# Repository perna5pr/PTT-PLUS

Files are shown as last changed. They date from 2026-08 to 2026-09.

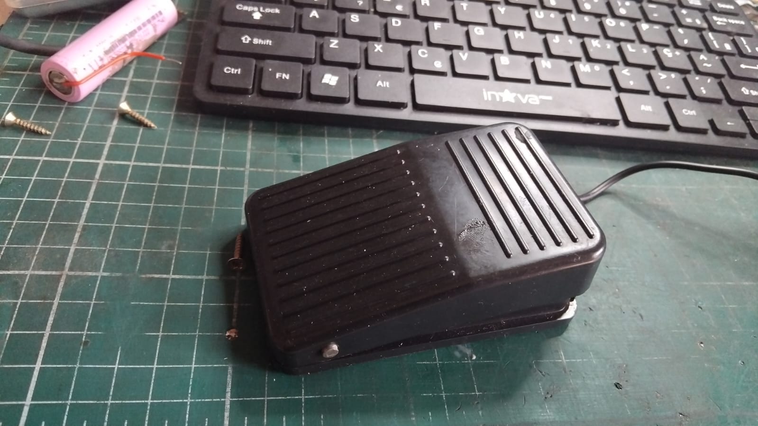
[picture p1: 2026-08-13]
hardware/Pedal-Mouse-PTT/Pedal_Mouse_PTT-foto.jpeg

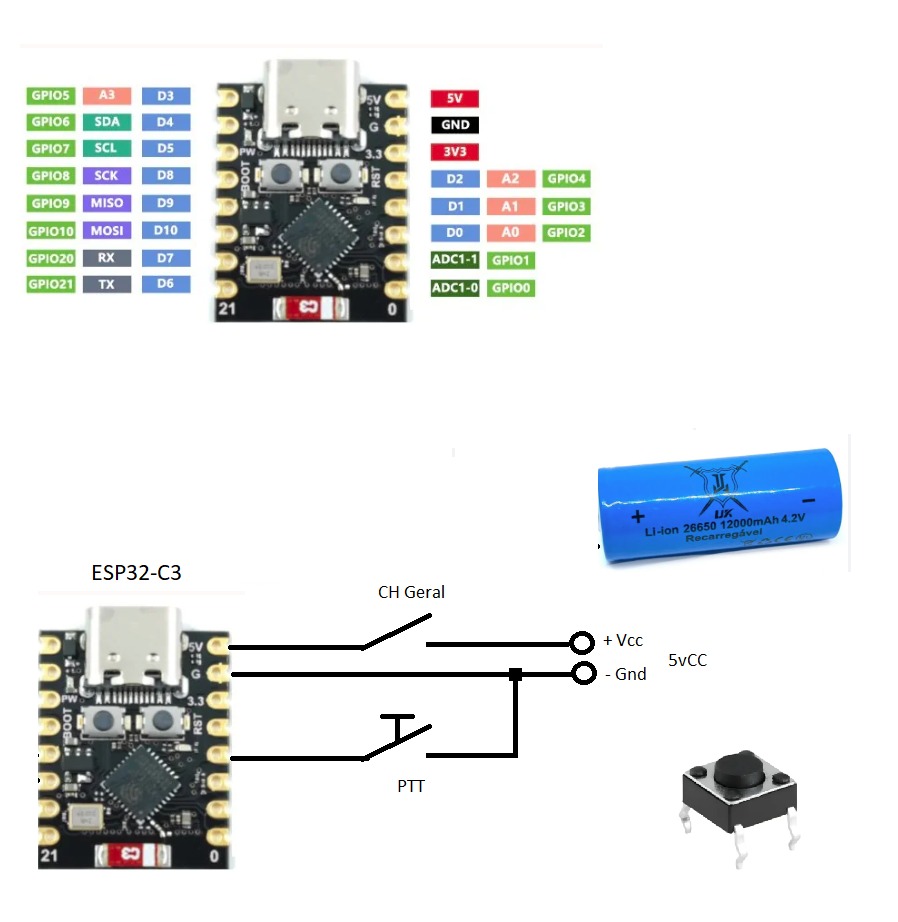
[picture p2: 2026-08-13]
hardware/Pedal-Mouse-PTT/Pedal_Mouse_PTT-diagrama.jpeg

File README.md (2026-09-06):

# 🤖 PTT-PLUS (1bt | 2bt | 4bt)
## Sistema de Automação com ESP32-C3 super mini para o APP CBTalk

Controle de comunicação sem fio de alta precisão baseado em Bluetooth Low Energy (BLE) projetado para automatizar comandos de clique e posicionamento de tela (emulação de mouse HID) no aplicativo CBTalk. O sistema possui temporização inteligente de segurança, interface visual em display compacto de 0.42" e calibração de coordenadas interativa gravada na memória Flash do circuito.

---

## Licenças

### Conteúdo
Este projeto utiliza a licença Creative Commons BY-NC-SA 4.0.


### Software
O código-fonte deste projeto está licenciado sob GPLv3.


### Hardware
O projeto de hardware está licenciado sob CERN-OHL-S.


### Filosofia do projeto
Open Source Hardware can Learn from Software - OSS & OSHW



---

## 🧠 Funcionamento do Algoritmo e Lógica de Controle

O fluxo de execução contínuo do firmware baseia-se em varredura ativa (*polling*) com tempo de ciclo controlado por um `delay(10)` para estabilização de leitura:

1. **Segmentação de Passos HID (Mouse)**: O protocolo Bluetooth clássico limita comandos nativos do mouse a um deslocamento máximo de -127 a +127 pixels por pacote de transmissão. A função `moveMouseSegmented()` fraciona distâncias longas automaticamente e introduz uma pausa de `50ms` para estabilização da interface de toque no smartphone.
2. **Ciclo de Segurança PTT (Anti-Bloqueio)**: Ao ativar a transmissão por voz, o controlador monitora o canal continuamente. Se o temporizador ultrapassar o limite de segurança de `90 segundos`, uma rotina de interrupção força a liberação do clique esquerdo (`mouse.release`) para não ocupar os canais públicos do CBTalk em transmissões acidentais.
3. **Modulação do LED de Feedback**: O pino `GPIO8` opera em modo intermitente comandado por relógio de software (`millis()`). A frequência visual do LED onboard do ESP32-C3 altera-se dinamicamente para sinalizar ao operador o tempo de portadora restante.
4. **Alinhamento Absoluto**: Como dispositivos móveis utilizam coordenadas relativas para emulação de mouses, a rotina `resetCursorPosition()` força intencionalmente o cursor para a borda extrema superior direita `(2000, -2000)` antes de realizar qualquer movimento mapeado. Isso garante que o cálculo em pixel parta sempre do mesmo ponto zero de referência da tela.
5. **Chaveamento Dinâmico do Gatilho**: A variável `PTT_TOGGLE_MODE` define o comportamento do botão principal:
   * **Modo Alternado (`true`)**: Um clique inicial dispara a função `startPTT()`. O estado permanece ativo até que um novo clique execute a rotina `stopPTT()`.
   * **Modo Pressionado (`false`)**: A transmissão ocorre estritamente na transição de descida do sinal (`LOW`), e o encerramento é chamado imediatamente na borda de subida (`HIGH`), emulando um microfone de rádio transceptor tradicional.
6. **Entrada Segura na Calibração**: O modo de ajuste de coordenadas exige que o `BUTTON_PIN3` e o `BUTTON_PIN4` entrem em nível lógico baixo (`LOW`) de forma simultânea. O algoritmo valida se o PTT está inativo (`!isPttActive`) antes de permitir o desvio para a calibração, impedindo que ruídos ou cliques acidentais quebrem a operação de voz.

---

## 🔌 Engenharia de Hardware e Esquema Elétrico (EasyEDA)

O design da placa de circuito impresso (PCB) foi desenvolvido no EasyEDA focado em tamanho reduzido para integração em caixas compactas, utilizando o barramento nativo do ESP32-C3 Super Mini.

### 🎛️ Diagrama de Conexões e Netlist

A distribuição das conexões elétricas das chaves táteis e do barramento de comunicação obedece à seguinte arquitetura de malha tratada no arquivo de fabricação:

*   **Barramento GND Comum:** Todas as 4 chaves táteis (`BT01` a `BT04`) compartilham um nó elétrico de aterramento unificado conectado diretamente ao pino `GND` do ESP32-C3.
*   **Malhas de Sinal (Trilhas de Controle):**
    *   **BT01 (PTT / Cima):** Conectado diretamente ao pino de entrada `GPIO 1`.
    *   **BT02 (Detalhes / Baixo):** Conectado diretamente ao pino de entrada `GPIO 2`.
    *   **BT03 (Lista / Direita):** Conectado diretamente ao pino de entrada `GPIO 3`.
    *   **BT04 (Mute / Esquerda):** Conectado diretamente ao pino de entrada `GPIO 4`.
*   **Interface I2C do Display OLED (0.42"):**
    *   Linha de Dados (`SDA`) roteada de forma isolada para o pino `GPIO 5`.
    *   Linha de Clock (`SCL`) roteada de forma paralela para o pino `GPIO 6`.

### 🛠️ Lista de Materiais de Referência (BOM - Bill of Materials)

| Qtd | Identificador na PCB | Componente Técnico | Tipo / Encapsulamento | Função no Circuito |
| :--- | :--- | :--- | :--- | :--- |
| 1 | U1 | ESP32-C3 Super Mini | SMD Dev Board | Microcontrolador central e interface BLE |
| 4 | BT01 a BT04 | Chaves Táteis Push-Button | 2 pinos / 4.3mm (ou similar) | Entrada de comandos de automação |
| 1 | DISP1 | Display OLED 0.42" 72x40 | SSD1306 I2C (4 pinos) | Feedback visual de estados e contagem |
| 1 | LED1 | LED de Status Integrado | Onboard (GPIO 8) | Alertas regressivos visuais de transmissão |

> ⚠️ **Nota de Montagem:** Como os pinos de entrada `GPIO 1` a `GPIO 4` estão configurados no firmware com resistores internos ativados (`INPUT_PULLUP`), não é necessária a adição de resistores de pull-up externos de 10kΩ na placa, simplificando o layout de trilhas.

---

## 📜 Licença e Termos de Uso

Este projeto é de código e hardware abertos, protegido sob o conceito híbrido **CC BY-NC-SA 4.0** (Atribuição-NãoComercial-CompartilhaIgual):

*   👥 **Atribuição:** Você é livre para montar, testar e alterar este projeto, desde que dê os devidos créditos aos desenvolvedores originais.
*   🛑 **Não Comercial:** É proibida a comercialização de placas montadas baseadas nesses circuitos ou a venda do firmware embarcado sem licenciamento dedicado das partes.
*   🔄 **CompartilhaIgual:** Qualquer projeto derivado ou modificação gerada a partir deste repositório deve obrigatoriamente manter a mesma licença aberta e não-comercial.

Este projeto utiliza licenças diferentes para cada tipo de material. A licença aplicável depende do conteúdo que está sendo utilizado.

### 📄 Conteúdo e documentação

A documentação, textos, imagens, diagramas e demais materiais criativos deste projeto são disponibilizados sob a:

<a href="https://creativecommons.org/licenses/by-nc-sa/4.0/">
  
</a>

**Creative Commons Attribution-NonCommercial-ShareAlike 4.0 International (CC BY-NC-SA 4.0)**

Você pode compartilhar e adaptar este material, desde que:

* dê os devidos créditos ao autor;
* não utilize o material para fins comerciais;
* distribua adaptações sob a mesma licença;
* mantenha os avisos de atribuição e licença aplicáveis.

[Leia o texto completo da CC BY-NC-SA 4.0](https://creativecommons.org/licenses/by-nc-sa/4.0/).

---

### 💻 Software

O código-fonte deste projeto é disponibilizado sob a:

<a href="https://www.gnu.org/licenses/gpl-3.0.html">
  GNU GPLv3
</a>

**GNU General Public License v3.0 (GPLv3)**

O software pode ser usado, estudado, modificado e redistribuído de acordo com os termos da GPLv3.

[Leia o texto completo da GNU GPLv3](https://www.gnu.org/licenses/gpl-3.0.html).

---

### 🔧 Hardware

O hardware, incluindo esquemas, arquivos de projeto, layouts, modelos e demais arquivos necessários para sua fabricação e modificação, é disponibilizado sob a:

<a href="https://ohwr.org/cern_ohl_s_v2.txt">
  CERN Open Hardware Licence
</a>

**CERN Open Hardware Licence Version 2 – Strongly Reciprocal (CERN-OHL-S-2.0)**

O hardware pode ser estudado, fabricado, modificado e redistribuído de acordo com os termos da CERN-OHL-S-2.0, respeitando suas condições de reciprocidade.

[Leia o texto completo da CERN-OHL-S-2.0](https://ohwr.org/cern_ohl_s_v2.txt).

---

### 🌐 Filosofia: Open Source Hardware can Learn from Software

> **Open Source Hardware can Learn from Software**

Este projeto adota a filosofia de que o desenvolvimento de hardware aberto pode se beneficiar dos princípios, práticas e da cultura desenvolvidos no ecossistema de software livre e open source.

<a href="https://www.open-electronics.org/what-can-open-source-hardware-learn-from-software/">
  Open Source Hardware can Learn from Software
</a>

Assim como no software, o projeto busca incentivar:

* **transparência** — disponibilização dos arquivos e informações necessárias para compreender o projeto;
* **liberdade** — possibilidade de estudar, modificar e adaptar o projeto;
* **colaboração** — incentivo à participação e ao desenvolvimento por terceiros;
* **compartilhamento** — possibilidade de distribuir o projeto e suas modificações de acordo com a licença aplicável;
* **reprodutibilidade** — disponibilização dos arquivos necessários para que outras pessoas possam reproduzir o hardware.

**“Open Source Hardware can Learn from Software” não constitui uma licença jurídica adicional.** A licença legal aplicável ao hardware deste projeto é a **CERN-OHL-S-2.0**.

---

### ⚖️ Resumo

| Material | Licença / Princípio |
| --- | --- |
| 📄 Documentação, textos, imagens e outros conteúdos criativos | CC BY-NC-SA 4.0 |
| 💻 Código-fonte e software | GNU GPLv3 |
| 🔧 Hardware e arquivos de projeto | CERN-OHL-S-2.0 |
| 🌐 Filosofia do projeto | Open Source Hardware can Learn from Software |

> **Importante:** cada licença se aplica ao respectivo tipo de material. O conteúdo criativo, o software e o hardware possuem termos de licenciamento distintos. Consulte a licença correspondente antes de redistribuir ou modificar qualquer parte deste projeto.

---

## 👥 Colaboradores e Créditos

Agradecimento especial aos desenvolvedores que projetaram e integraram este sistema (Usuários do CBTalk):

*   ⚡ `~ CASSA VAGABUNDO`
*   ⌨️ `_PERNA-5-PR_`
*   🛠️ `!# _TECNICO_ / SC`

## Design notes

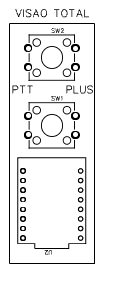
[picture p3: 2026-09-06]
hardware/PTT_PLUS_2bt/PCB_PTT_PLUS_2bt_2026-09-06_frente.png

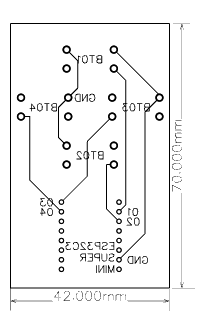
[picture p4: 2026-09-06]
hardware/PTT_PLUS_4bt/PCB_PTT_PLUS_4bt_2026-09-06_tras.png

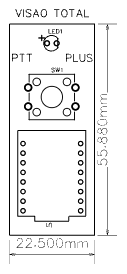
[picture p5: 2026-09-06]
hardware/PTT_PLUS_1bt/PCB_PTT_PLUS_1bt_2026-09-06_frente.png

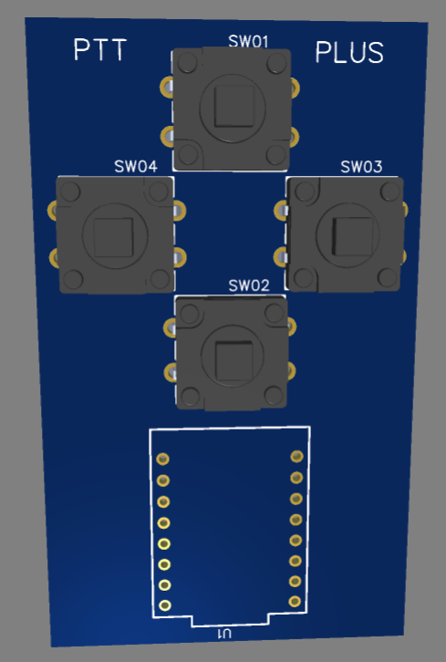
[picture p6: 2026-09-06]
hardware/PTT_PLUS_4bt/PCB_PTT_PLUS_4bt_3D_frente.png

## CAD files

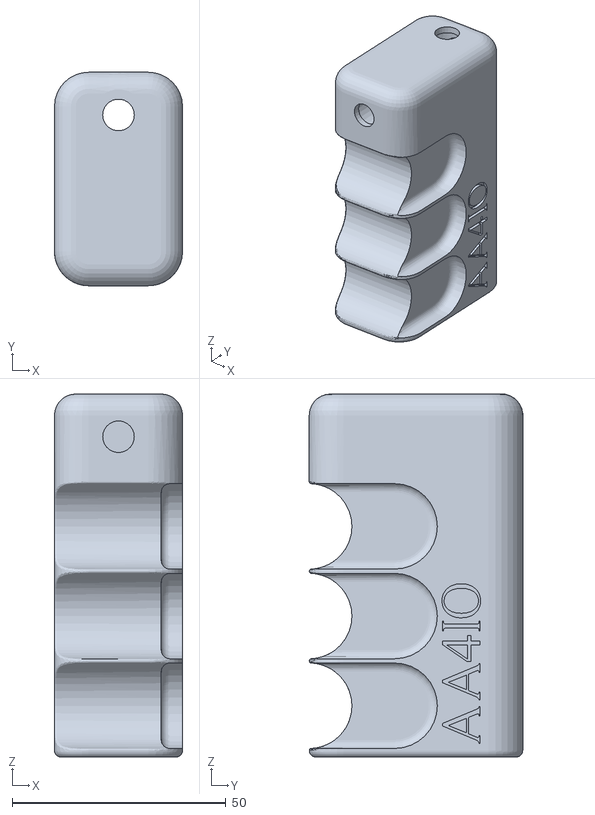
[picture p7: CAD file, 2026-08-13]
hardware/PTT_PLUS_2bt/ptt-2bt.stl
30.0 x 50.0 x 85.0

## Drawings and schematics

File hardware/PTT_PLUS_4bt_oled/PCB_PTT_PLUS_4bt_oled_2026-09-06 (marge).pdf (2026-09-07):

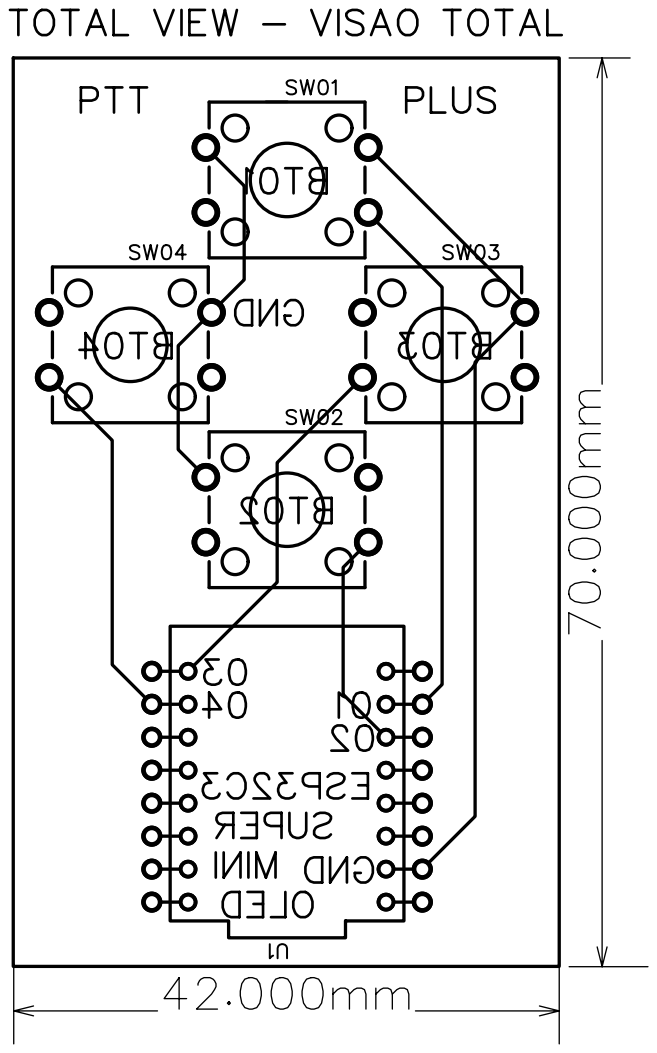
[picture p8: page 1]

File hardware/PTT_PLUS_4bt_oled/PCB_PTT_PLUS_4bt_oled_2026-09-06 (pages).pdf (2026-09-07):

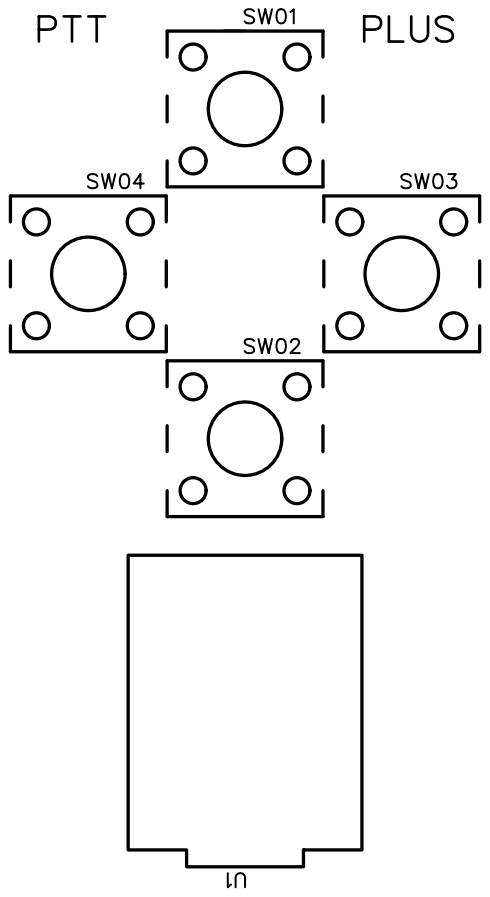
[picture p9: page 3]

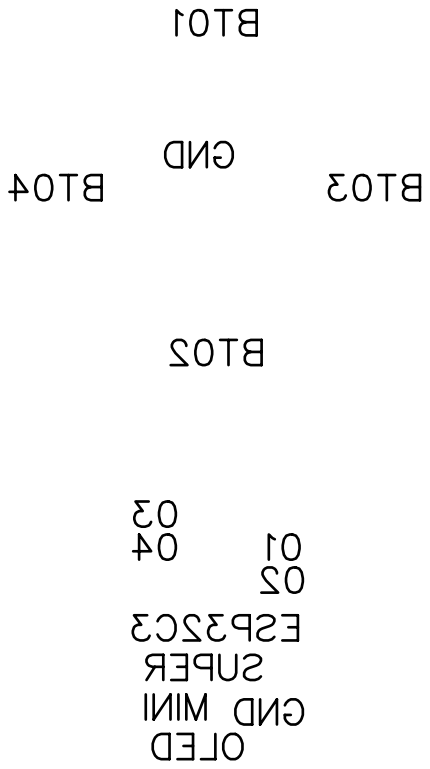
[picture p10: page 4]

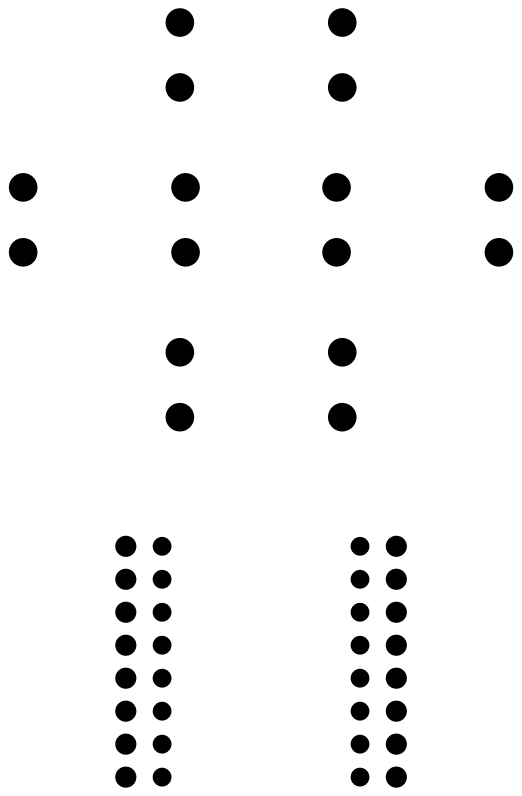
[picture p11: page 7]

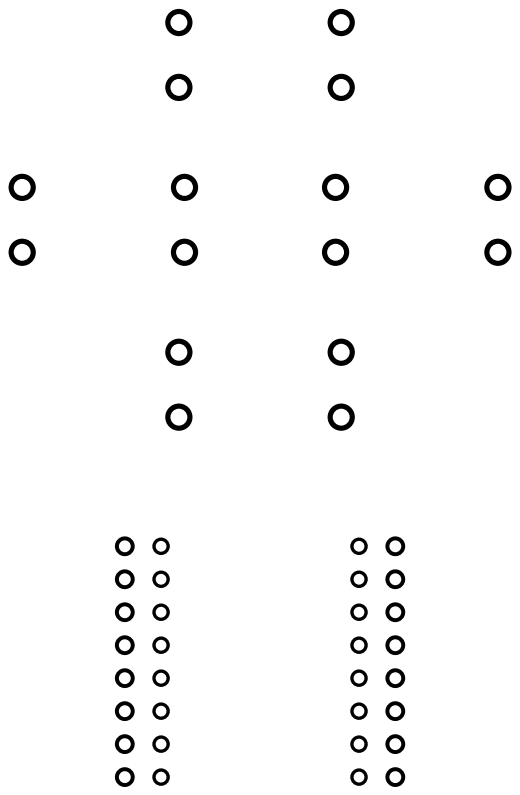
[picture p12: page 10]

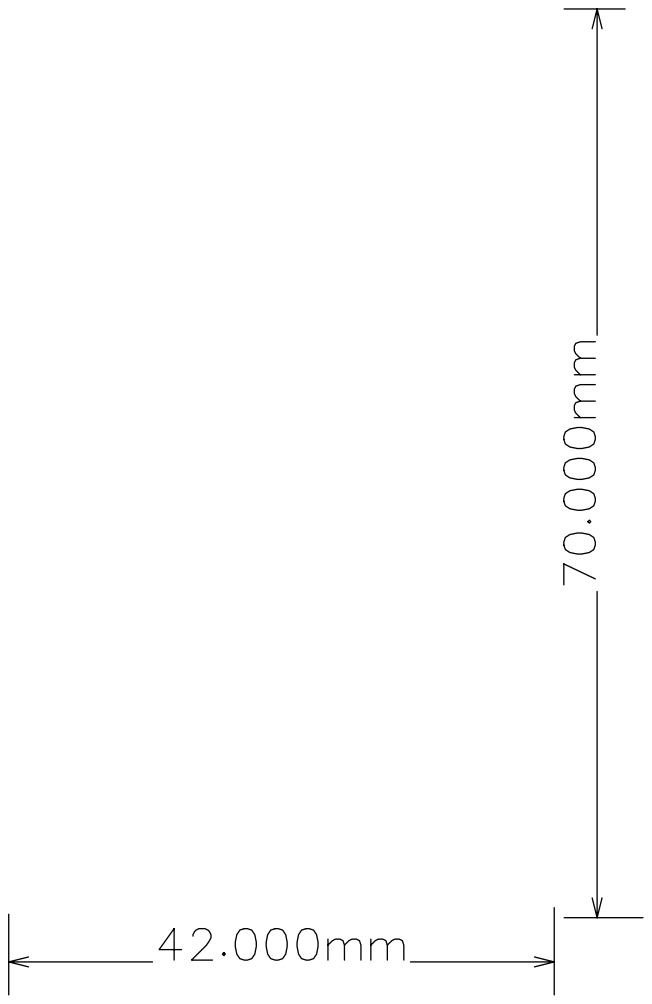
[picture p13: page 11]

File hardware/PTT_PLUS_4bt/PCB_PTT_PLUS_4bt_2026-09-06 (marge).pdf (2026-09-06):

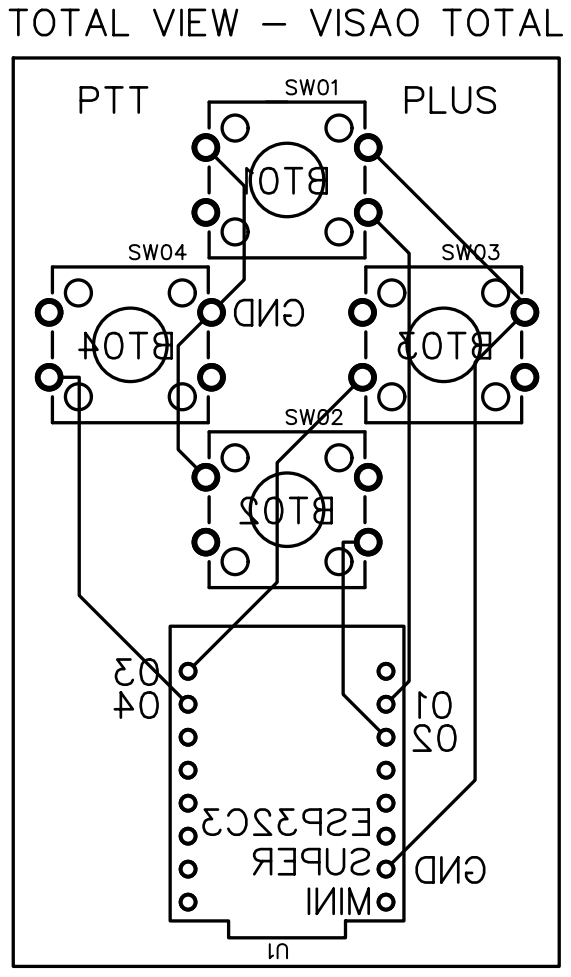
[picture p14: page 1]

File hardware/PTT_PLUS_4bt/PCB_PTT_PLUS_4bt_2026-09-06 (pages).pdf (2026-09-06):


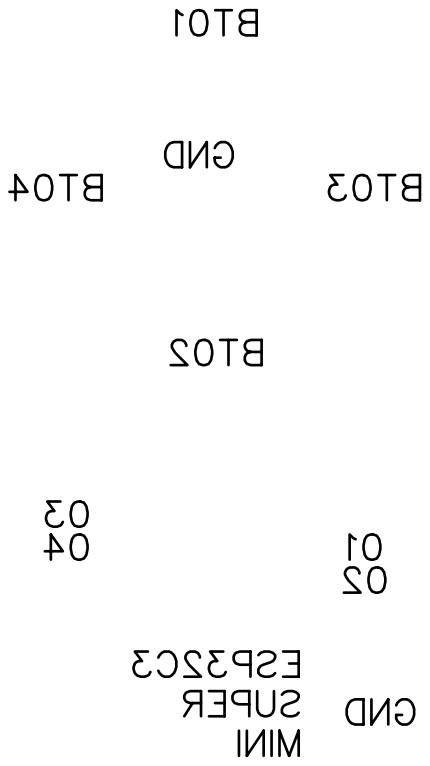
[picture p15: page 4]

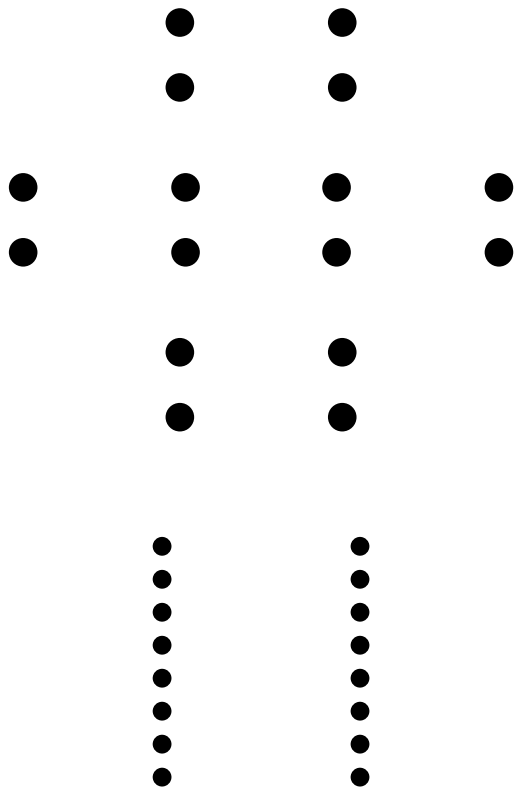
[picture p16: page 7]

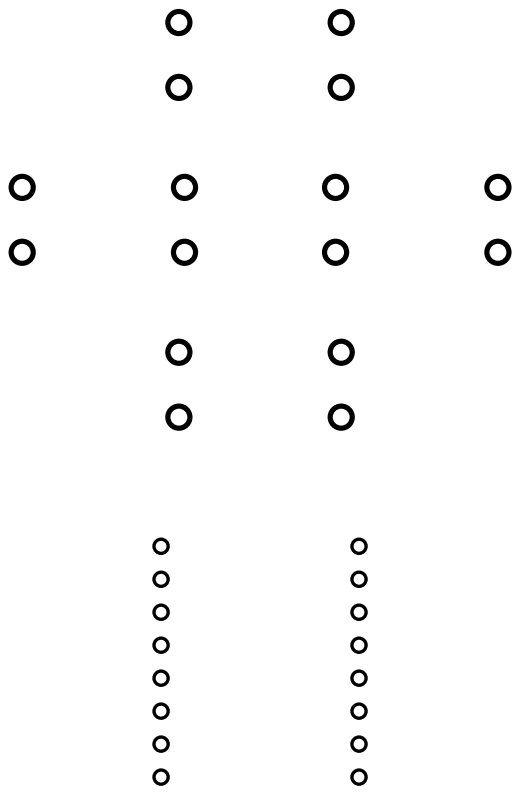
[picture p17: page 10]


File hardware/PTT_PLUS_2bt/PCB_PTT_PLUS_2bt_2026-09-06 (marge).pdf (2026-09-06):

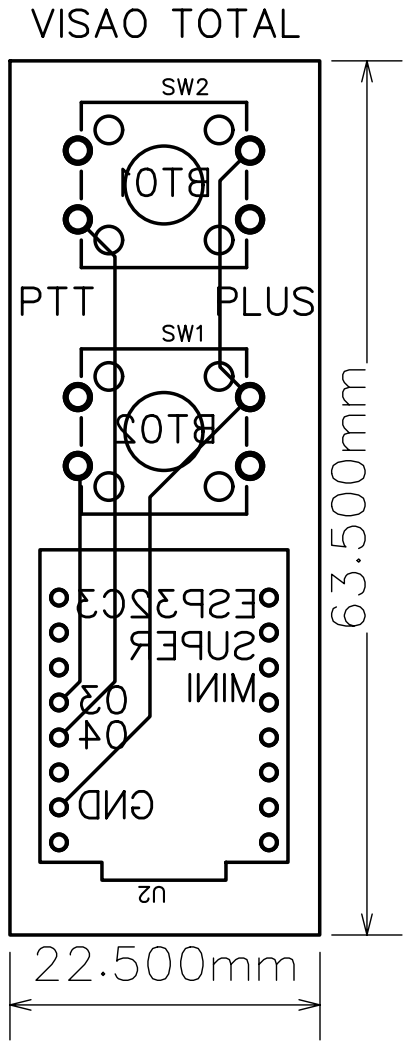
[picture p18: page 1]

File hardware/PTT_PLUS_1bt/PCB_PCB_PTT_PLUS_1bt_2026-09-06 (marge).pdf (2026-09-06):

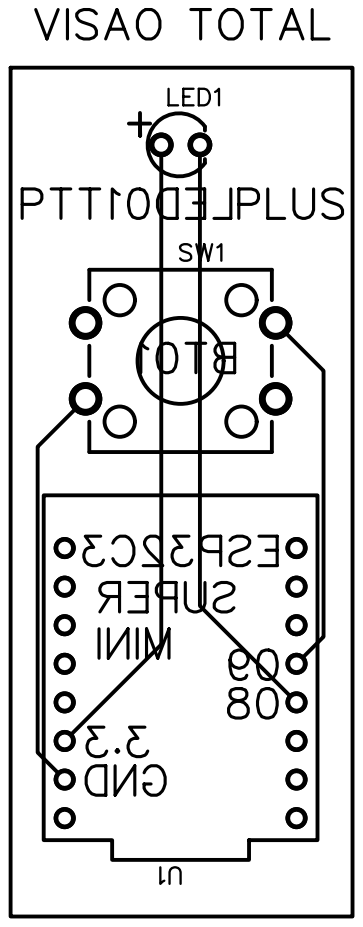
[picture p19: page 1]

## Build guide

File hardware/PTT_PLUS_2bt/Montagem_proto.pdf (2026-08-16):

# PTT 1 botão

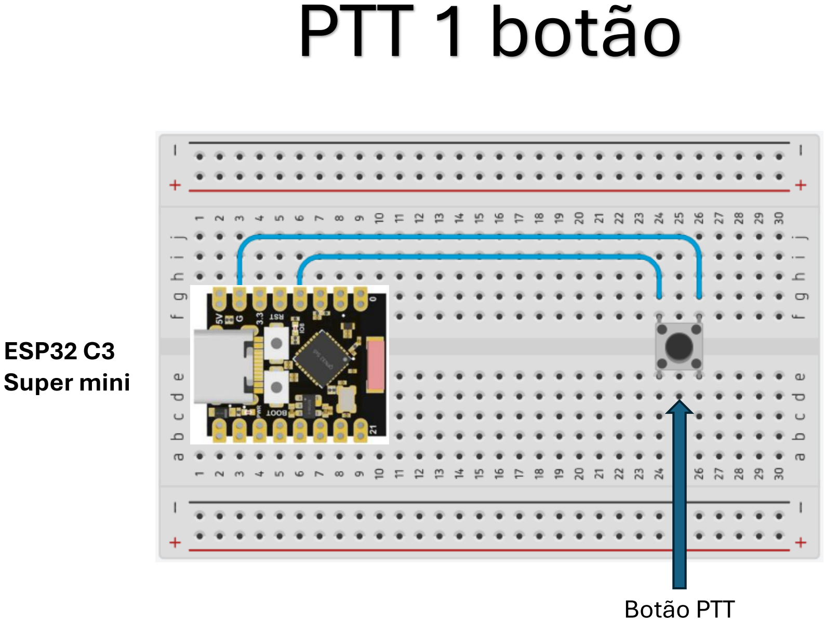
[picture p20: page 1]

Botão PTT

ESP32 C3
Super mini

# PTT 2 botões

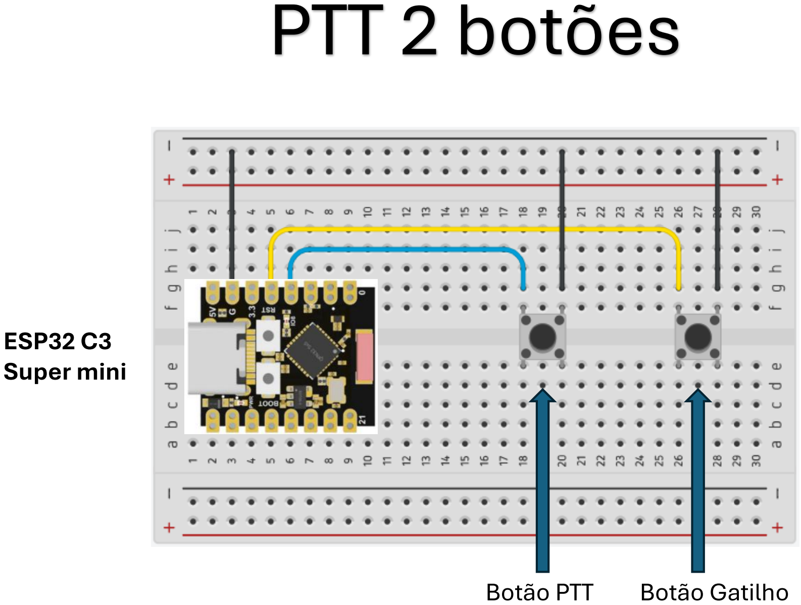
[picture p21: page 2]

Botão PTT Botão Gatilho

ESP32 C3
Super mini

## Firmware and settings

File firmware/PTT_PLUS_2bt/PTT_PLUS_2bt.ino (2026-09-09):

#include <Arduino.h>
#include <HijelHID_BLEMouse.h>
#include <Preferences.h>

// Instância do Mouse BLE com nome e fabricante personalizados
HijelBLEMouse mouse("PTT_PLUS_2bt", "MOSAICO", 100);

// Configuração dos Pinos dos Botões (GPIO 3 e GPIO 4 no ESP32-C3)
const int BUTTON_PIN1 = 3;
const int BUTTON_PIN2 = 4;
const int PINO_BOOT = 9;  // Botão BOOT onboard do ESP32-C3 SuperMini, usado para calibração

Preferences preferences;

// --- LED onboard simples (azul, GPIO8 no ESP32-C3 SuperMini) ---
const int LED_PIN = 8;
const bool LED_ACTIVE_LOW = true;  // na maioria das SuperMini o LED acende com GPIO em LOW.
                                    // Se o LED ficar invertido (aceso quando devia estar apagado), mude para false.

bool ledOn = false;                 // estado lógico atual do LED (para controlar o pisca-pisca)
unsigned long lastLedToggle = 0;

const unsigned long LED_WARN_SLOW_THRESHOLD_MS = 30000;  // a partir daqui (30s restantes) começa a piscar devagar
const unsigned long LED_WARN_FAST_THRESHOLD_MS = 10000;  // a partir daqui (10s restantes) pisca rápido
const unsigned long LED_BLINK_SLOW_MS = 500;              // intervalo do pisca devagar
const unsigned long LED_BLINK_FAST_MS = 150;               // intervalo do pisca rápido

// --- Posições calibráveis dos cliques na tela (salvas na memória flash) ---
int16_t ptt1X = -25;
int16_t ptt1Y = 130;
int16_t btn2X = -125;
int16_t btn2Y = 65;

// --- Controle de entrada no modo calibração (segurar BOOT por 5s) ---
bool bootHeld = false;
unsigned long bootPressStart = 0;
const unsigned long BOOT_HOLD_TO_CALIBRATE_MS = 5000;

// --- BOTÃO 1 (PTT) ---
bool isPressed1 = false;      // true enquanto o PTT está ativo (transmitindo)
bool isLocked1 = false;       // true quando travado via clique rápido
int lastButtonState1 = HIGH;  // última leitura bruta (para debounce)
bool stableState1 = HIGH;     // último estado já confirmado/debounced
unsigned long lastDebounceTime1 = 0;
unsigned long pressStartTime1 = 0;  // quando o botão foi pressionado (p/ distinguir clique de hold)
unsigned long timePTT = 0;          // quando o PTT ligou (p/ trava de segurança de 90s e contagem do LED)

// --- BOTÃO 2 ---
bool isPressed2 = false;
int lastButtonState2 = HIGH;
unsigned long lastDebounceTime2 = 0;

const unsigned long DEBOUNCE_DELAY = 50;
const unsigned long CLICK_THRESHOLD_MS = 300;  // abaixo disso = "clique" (trava); acima = "hold"
const unsigned long PTT_MAX_HOLD_MS = 90000;   // trava de segurança: solta sozinho após 90s

// Variável de controle para posicionamento inicial único pós-conexão
bool isPositioned = false;

// Armazena o estado anterior da conexão Bluetooth
bool lastPairedState = false;

void setup() {
  Serial.begin(115200);
  Serial.println("Iniciando PTT_PLUS 2bt");

  // Configura os botões com Pull-Up interno
  pinMode(BUTTON_PIN1, INPUT_PULLUP);
  pinMode(BUTTON_PIN2, INPUT_PULLUP);
  pinMode(PINO_BOOT, INPUT_PULLUP);

  // Inicializa o LED apagado
  pinMode(LED_PIN, OUTPUT);
  setLed(false);

  loadCalibrationFromNVS();

  // Inicializa o serviço BLE Mouse
  mouse.begin();

  delay(1000);
}

// Liga/desliga o LED fisicamente, respeitando a polaridade da placa
void setLed(bool on) {
  bool physicalHigh = LED_ACTIVE_LOW ? !on : on;
  digitalWrite(LED_PIN, physicalHigh ? HIGH : LOW);
  ledOn = on;
}

// Move o cursor em passos de no maximo 127 unidades (limite do protocolo HID),
// dividindo automaticamente deslocamentos maiores.
void moveMouseSegmented(int16_t totalX, int16_t totalY) {
  int16_t remX = totalX;
  int16_t remY = totalY;
  while (remX != 0 || remY != 0) {
    int8_t stepX = (int8_t)constrain(remX, -127, 127);
    int8_t stepY = (int8_t)constrain(remY, -127, 127);
    mouse.moveTo(stepX, stepY);
    remX -= stepX;
    remY -= stepY;
    delay(50);
  }
}

void loadCalibrationFromNVS() {
  preferences.begin("ptt_calib", true);
  ptt1X = preferences.getShort("b1_x", -25);
  ptt1Y = preferences.getShort("b1_y", 130);
  btn2X = preferences.getShort("b2_x", -125);
  btn2Y = preferences.getShort("b2_y", 65);
  preferences.end();
  Serial.printf("Posições carregadas: Botao1 X=%d Y=%d | Botao2 X=%d Y=%d\n", ptt1X, ptt1Y, btn2X, btn2Y);
}

void saveCalibrationToNVS() {
  preferences.begin("ptt_calib", false);
  preferences.putShort("b1_x", ptt1X);
  preferences.putShort("b1_y", ptt1Y);
  preferences.putShort("b2_x", btn2X);
  preferences.putShort("b2_y", btn2Y);
  preferences.end();
  Serial.println("Posições salvas na memória flash (NVS)!");
}

// Modo de calibração: segurar o BOOT por 5s entra aqui. Configuração 100% pelo
// Serial Monitor (digite 'X,Y' + Enter para mover o cursor até lá, e 'ok' ou o
// próprio BOOT para confirmar). Passa pelos 2 botões em sequência.
void runCalibrationMode() {
  Serial.println("\n=======================================================");
  Serial.println(">>> MODO DE CALIBRAÇÃO ATIVADO (BOOT segurado por 5s)! <<<");
  Serial.println("=======================================================\n");

  Serial.println("Entrando no modo de calibracao... aguarde.");
  setLed(true);
  delay(3000);
  setLed(false);

  while (digitalRead(PINO_BOOT) == LOW) {
    delay(10);
  }
  delay(200);

  Serial.println("----------------------------------------------------------------------------------");
  Serial.println("Para cada botão, digite 'X,Y' + Enter (ex: -25,130) para mover o cursor até lá,");
  Serial.println("a partir do canto. Repita quantas vezes quiser até acertar. Depois digite 'ok'");
  Serial.println("(ou aperte o BOOT) para confirmar e passar para o próximo.");
  Serial.println("O LED faz N piscadas no primeiro segundo (N = numero do botao) e apaga no seguinte.");
  Serial.println("----------------------------------------------------------------------------------\n");

  int16_t targetCoordsX[2] = { ptt1X, btn2X };
  int16_t targetCoordsY[2] = { ptt1Y, btn2Y };

  for (int i = 0; i < 2; i++) {
    Serial.printf(">>> CONFIGURANDO BOTÃO %d <<< (LED pisca %d vez(es) por segundo)\n", i + 1, i + 1);

    mouse.moveTo(2000, -2000);  // reseta o cursor no canto
    delay(300);

    while (digitalRead(PINO_BOOT) == LOW) {
      delay(10);
    }
    delay(200);

    const unsigned long blinksThisButton = (unsigned long)(i + 1);
    const unsigned long halfPeriod = 500UL / blinksThisButton;
    bool lastLedComputed = false;

    int16_t currentX = 0;
    int16_t currentY = 0;
    bool stepConfirmed = false;

    while (!stepConfirmed) {
      bool confirmNow = (digitalRead(PINO_BOOT) == LOW);

      if (Serial.available()) {
        String cmd = Serial.readStringUntil('\n');
        cmd.trim();
        if (cmd.length() > 0) {
          String cmdLower = cmd;
          cmdLower.toLowerCase();
          if (cmdLower == "ok" || cmdLower == "enter") {
            confirmNow = true;
          } else {
            int commaIndex = cmd.indexOf(',');
            if (commaIndex > 0) {
              int16_t targetX = (int16_t)cmd.substring(0, commaIndex).toInt();
              int16_t targetY = (int16_t)cmd.substring(commaIndex + 1).toInt();
              int16_t deltaX = targetX - currentX;
              int16_t deltaY = targetY - currentY;
              moveMouseSegmented(deltaX, deltaY);
              currentX = targetX;
              currentY = targetY;
              Serial.printf("  Cursor movido para X=%d Y=%d (a partir do canto)\n", currentX, currentY);
            } else {
              Serial.println("  Comando nao reconhecido. Use 'X,Y' (ex: -25,130) ou 'ok'.");
            }
          }
        }
      }

      // LED: N piscadas no primeiro segundo do ciclo de 2s, apagado no segundo seguinte
      unsigned long cyclePos = millis() % 2000;
      bool shouldBeOn;
      if (cyclePos < 1000) {
        shouldBeOn = ((cyclePos / halfPeriod) % 2) == 0;
      } else {
        shouldBeOn = false;
      }
      if (shouldBeOn != lastLedComputed) {
        lastLedComputed = shouldBeOn;
        setLed(shouldBeOn);
      }

      if (confirmNow) {
        targetCoordsX[i] = currentX;
        targetCoordsY[i] = currentY;
        Serial.printf("-> Botão %d SALVO! X=%d Y=%d\n\n", i + 1, currentX, currentY);

        for (int flash = 0; flash < 3; flash++) {
          setLed(true);
          delay(80);
          setLed(false);
          delay(80);
        }

        stepConfirmed = true;
        while (digitalRead(PINO_BOOT) == LOW) {
          delay(10);
        }
        delay(300);
      }

      delay(10);
    }
  }

  ptt1X = targetCoordsX[0];
  ptt1Y = targetCoordsY[0];
  btn2X = targetCoordsX[1];
  btn2Y = targetCoordsY[1];

  saveCalibrationToNVS();

  Serial.println("\n=======================================================");
  Serial.println("Calibração concluída! Os 2 botões foram salvos.");
  Serial.println("=======================================================\n");

  setLed(false);
  mouse.moveTo(2000, -2000);
}

// Atualiza o LED a cada volta do loop, sem bloquear nada.
// Regras:
//  - Fora de transmissão -> apagado
//  - Segurando (hold, sem estar travado) -> aceso fixo
//  - Travado (clique) -> aceso fixo até faltarem 30s do timeout de 90s,
//    depois pisca devagar, e piscando rápido nos últimos 10s
void atualizarLed() {
  if (!isPressed1) {
    if (ledOn) setLed(false);
    return;
  }

  if (!isLocked1) {
    // Modo "segurando": aceso fixo enquanto o dedo estiver no botão
    if (!ledOn) setLed(true);
    return;
  }

  // Modo travado: calcula quanto tempo falta para o timeout de segurança
  unsigned long elapsed = millis() - timePTT;
  long remaining = (long)PTT_MAX_HOLD_MS - (long)elapsed;
  if (remaining < 0) remaining = 0;

  if (remaining > LED_WARN_SLOW_THRESHOLD_MS) {
    // Mais de 30s restantes -> aceso fixo
    if (!ledOn) setLed(true);
  } else {
    unsigned long blinkInterval =
        (remaining > LED_WARN_FAST_THRESHOLD_MS) ? LED_BLINK_SLOW_MS : LED_BLINK_FAST_MS;
    if (millis() - lastLedToggle >= blinkInterval) {
      lastLedToggle = millis();
      setLed(!ledOn);
    }
  }
}

// Liga o PTT: posiciona o cursor e pressiona o clique esquerdo
void ativarPTT() {
  isPressed1 = true;
  moveMouseSegmented(ptt1X, ptt1Y);
  mouse.press(MouseButton::Left);  // press()/release() não bloqueiam
  Serial.println("Botao 1: PTT ativado");
}

// Solta o PTT e devolve o cursor para o canto
void liberarPTT() {
  isPressed1 = false;
  mouse.release(MouseButton::Left);
  delay(50);
  mouse.moveTo(2000, -2000);
  delay(50);
  Serial.println("Botao 1: PTT liberado. Cursor de volta ao canto.");
}

void loop() {
  bool isConnected = mouse.isPaired();

  // Executado quando o status do Bluetooth muda (Conectou ou Desconectou)
  if (isConnected != lastPairedState) {
    lastPairedState = isConnected;
    if (isConnected) {
      Serial.println("CBTalk - CONECTADO - PRONTO");
      if (!isPositioned) {
        Serial.println("Celular conectado! Alinhando cursor no canto superior direito...");
        delay(400);  // Aguarda estabilização da conexão BLE do Android

        mouse.moveTo(2000, -2000);
        delay(50);

        isPositioned = true;
        Serial.println("Cursor posicionado sobre o PTT! Transmissão instantânea pronta.");
      }
    } else {
      Serial.println("CBTalk - DESCONECTADO - Aguardando");
      if (isPositioned) {
        Serial.println("Bluetooth desconectado. Aguardando reconexão...");
        isPositioned = false;
      }
      // Se caiu a conexão com o PTT ativo, zera o estado local
      isPressed1 = false;
      isLocked1 = false;
      isPressed2 = false;
    }
  }

  // Executa as ações apenas quando o celular estiver conectado
  if (isConnected) {
    // Entrada na calibração: segurar o botão BOOT por 5 segundos
    bool bootPressedNow = (digitalRead(PINO_BOOT) == LOW);
    if (bootPressedNow && !isPressed1) {
      if (!bootHeld) {
        bootHeld = true;
        bootPressStart = millis();
      } else if (millis() - bootPressStart >= BOOT_HOLD_TO_CALIBRATE_MS) {
        bootHeld = false;
        runCalibrationMode();
        return;
      }
    } else {
      bootHeld = false;
    }

    int reading1 = digitalRead(BUTTON_PIN1);
    int reading2 = digitalRead(BUTTON_PIN2);

    // --- TRATAMENTO DO BOTÃO 1 (PTT: clique-trava + segurar-para-transmitir) ---
    if (reading1 != lastButtonState1) {
      lastDebounceTime1 = millis();
    }

    // Só processa quando o sinal estabilizou (debounce) E realmente mudou de estado
    if ((millis() - lastDebounceTime1) > DEBOUNCE_DELAY && reading1 != stableState1) {
      stableState1 = reading1;

      if (stableState1 == LOW) {
        // --- Borda de descida: botão foi pressionado agora ---
        if (isLocked1) {
          // Segundo clique enquanto travado -> destrava e solta
          isLocked1 = false;
          liberarPTT();
        } else if (!isPressed1) {
          // Início de um novo toque: liga o PTT na hora.
          // Ainda não sabemos se vai virar "clique" (trava) ou "hold" (soltar ao soltar o dedo).
          pressStartTime1 = millis();
          timePTT = millis();
          ativarPTT();
        }
      } else {
        // --- Borda de subida: botão foi solto agora ---
        if (isPressed1 && !isLocked1) {
          unsigned long heldFor = millis() - pressStartTime1;
          if (heldFor < CLICK_THRESHOLD_MS) {
            // Foi um clique rápido -> trava ligado, não solta o PTT
            isLocked1 = true;
            lastLedToggle = millis();  // começa o ciclo de pisca do LED do zero
            Serial.println("Botao 1: Clique detectado - PTT TRAVADO");
          } else {
            // Foi um hold -> solta o PTT agora que o dedo saiu
            liberarPTT();
          }
        }
      }
    }
    lastButtonState1 = reading1;

    // Trava de segurança: solta o PTT automaticamente após PTT_MAX_HOLD_MS,
    // seja no modo travado (clique) ou segurando (hold)
    if (isPressed1 && (millis() - timePTT) >= PTT_MAX_HOLD_MS) {
      Serial.println("Botao 1: Timeout de seguranca atingido, liberando PTT");
      isLocked1 = false;
      liberarPTT();
    }

    // --- TRATAMENTO DO BOTÃO 2 ---
    if (reading2 != lastButtonState2) {
      lastDebounceTime2 = millis();
    }

    if ((millis() - lastDebounceTime2) > DEBOUNCE_DELAY) {
      if (reading2 == LOW && !isPressed2 && !isPressed1) {
        isPressed2 = true;
        Serial.println("Botão 2: Detalhes do Usuario!");
        moveMouseSegmented(btn2X, btn2Y);
        mouse.click(MouseButton::Left, 50);
        delay(50);
      } else if (reading2 == HIGH && isPressed2) {
        isPressed2 = false;
        Serial.println("Botão 2 Solto!");
        mouse.moveTo(2000, -2000);
        delay(50);
      }
    }
    lastButtonState2 = reading2;

  } else {
    // Reseta as flags se perder a conexão Bluetooth
    isPressed1 = false;
    isLocked1 = false;
    isPressed2 = false;
  }

  // Atualiza o LED em toda volta do loop (não bloqueia nada)
  atualizarLed();

  delay(10);
}

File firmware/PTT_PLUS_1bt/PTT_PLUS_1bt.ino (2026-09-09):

#include <Arduino.h>
#include <HijelHID_BLEMouse.h>
#include <Preferences.h>

// Instância do Mouse BLE com nome e fabricante personalizados
HijelBLEMouse mouse("PTT_PLUS_1bt", "MOSAICO", 100);

#define PINO_PTT 9  // Mesmo pino do botao BOOT onboard do ESP32-C3 SuperMini
#define PINO_LED 8

Preferences preferences;

const bool LED_ACTIVE_LOW = true;  // no ESP32-C3 SuperMini o LED onboard do GPIO8 acende em LOW.
                                    // Se ficar invertido (aceso quando devia estar apagado), mude para false.

bool ledOn = false;
unsigned long lastLedToggle = 0;

const unsigned long LED_BLINK_WAITING_MS = 300;           // velocidade do pisca enquanto aguarda conexao
const unsigned long LED_WARN_SLOW_THRESHOLD_MS = 30000;   // a partir daqui (30s restantes) comeca a piscar devagar
const unsigned long LED_WARN_FAST_THRESHOLD_MS = 10000;   // a partir daqui (10s restantes) pisca rapido
const unsigned long LED_BLINK_SLOW_MS = 500;               // intervalo do pisca devagar
const unsigned long LED_BLINK_FAST_MS = 150;                // intervalo do pisca rapido

// --- Posição do clique do PTT na tela (calibrável, salva na memória flash) ---
int16_t pttX = -70;
int16_t pttY = 240;

// --- Controle de entrada no modo calibração ---
// Como este projeto so tem 1 botao (PINO_PTT = 9, o mesmo do BOOT onboard),
// a calibracao e acionada segurando o PROPRIO botao de PTT por 5s continuos.
const unsigned long BOOT_HOLD_TO_CALIBRATE_MS = 5000;
bool calibrationArmed = false;  // vira true assim que o hold ultrapassa 5s nesta pressao

// --- PTT ---
bool isPressed = false;       // true enquanto o PTT esta ativo (transmitindo)
bool isLocked = false;        // true quando travado via clique rapido
int lastButtonState = HIGH;   // ultima leitura bruta (para debounce)
bool stableState = HIGH;      // ultimo estado ja confirmado/debounced
unsigned long lastDebounceTime = 0;
unsigned long pressStartTime = 0;  // quando o botao foi pressionado (p/ distinguir clique de hold)
unsigned long timePTT = 0;         // quando o PTT ligou (p/ trava de seguranca de 90s e contagem do LED)

const unsigned long DEBOUNCE_DELAY = 50;
const unsigned long CLICK_THRESHOLD_MS = 300;  // abaixo disso = "clique" (trava); acima = "hold"
const unsigned long PTT_MAX_HOLD_MS = 90000;   // trava de seguranca: solta sozinho apos 90s

bool isConnected = false;
bool isPositioned = false;   // controle do posicionamento inicial do cursor pos-conexao
bool lastPairedState = false;

// Liga/desliga o LED fisicamente, respeitando a polaridade da placa
void setLed(bool on) {
  bool physicalHigh = LED_ACTIVE_LOW ? !on : on;
  digitalWrite(PINO_LED, physicalHigh ? HIGH : LOW);
  ledOn = on;
}

// Move o cursor em passos de no maximo 127 unidades (limite do protocolo HID),
// dividindo automaticamente deslocamentos maiores.
void moveMouseSegmented(int16_t totalX, int16_t totalY) {
  int16_t remX = totalX;
  int16_t remY = totalY;
  while (remX != 0 || remY != 0) {
    int8_t stepX = (int8_t)constrain(remX, -127, 127);
    int8_t stepY = (int8_t)constrain(remY, -127, 127);
    mouse.moveTo(stepX, stepY);
    remX -= stepX;
    remY -= stepY;
    delay(50);
  }
}

void loadCalibrationFromNVS() {
  preferences.begin("ptt_calib", true);
  pttX = preferences.getShort("ptt_x", -70);
  pttY = preferences.getShort("ptt_y", 240);
  preferences.end();
  Serial.printf("Posicao do PTT carregada: X=%d Y=%d\n", pttX, pttY);
}

void saveCalibrationToNVS() {
  preferences.begin("ptt_calib", false);
  preferences.putShort("ptt_x", pttX);
  preferences.putShort("ptt_y", pttY);
  preferences.end();
  Serial.println("Posicao do PTT salva na memoria flash (NVS)!");
}

// Modo de calibração: acionado ao segurar o próprio botão de PTT por 5s contínuos.
// Configuração 100% pelo Serial Monitor (digite 'X,Y' + Enter para mover o cursor
// até lá, e 'ok' ou o próprio botão para confirmar).
void runCalibrationMode() {
  Serial.println("\n=======================================================");
  Serial.println(">>> MODO DE CALIBRAÇÃO ATIVADO (botao segurado por 5s)! <<<");
  Serial.println("=======================================================\n");

  Serial.println("Entrando no modo de calibracao... aguarde.");
  setLed(true);
  delay(3000);
  setLed(false);

  while (digitalRead(PINO_PTT) == LOW) {
    delay(10);
  }
  delay(200);

  Serial.println("----------------------------------------------------------------------------------");
  Serial.println("Digite a posição absoluta 'X,Y' e Enter (ex: -70,240) para mover o cursor até lá,");
  Serial.println("a partir do canto. Repita quantas vezes quiser até acertar. Depois digite 'ok'");
  Serial.println("(ou aperte o botão) para confirmar e salvar.");
  Serial.println("O LED pisca 1x no primeiro segundo de cada ciclo de 2s, e apaga no segundo seguinte.");
  Serial.println("----------------------------------------------------------------------------------\n");

  mouse.moveTo(2000, -2000);  // reseta o cursor no canto antes de calibrar
  delay(300);

  int16_t currentX = 0;
  int16_t currentY = 0;
  bool lastLedComputed = false;
  bool stepConfirmed = false;

  while (!stepConfirmed) {
    bool confirmNow = (digitalRead(PINO_PTT) == LOW);

    if (Serial.available()) {
      String cmd = Serial.readStringUntil('\n');
      cmd.trim();
      if (cmd.length() > 0) {
        String cmdLower = cmd;
        cmdLower.toLowerCase();
        if (cmdLower == "ok" || cmdLower == "enter") {
          confirmNow = true;
        } else {
          int commaIndex = cmd.indexOf(',');
          if (commaIndex > 0) {
            int16_t targetX = (int16_t)cmd.substring(0, commaIndex).toInt();
            int16_t targetY = (int16_t)cmd.substring(commaIndex + 1).toInt();
            int16_t deltaX = targetX - currentX;
            int16_t deltaY = targetY - currentY;
            moveMouseSegmented(deltaX, deltaY);
            currentX = targetX;
            currentY = targetY;
            Serial.printf("  Cursor movido para X=%d Y=%d (a partir do canto)\n", currentX, currentY);
          } else {
            Serial.println("  Comando nao reconhecido. Use 'X,Y' (ex: -70,240) ou 'ok'.");
          }
        }
      }
    }

    // LED: 1 piscada no primeiro segundo de cada ciclo de 2s, apagado no segundo seguinte
    unsigned long cyclePos = millis() % 2000;
    bool shouldBeOn = (cyclePos < 500);
    if (shouldBeOn != lastLedComputed) {
      lastLedComputed = shouldBeOn;
      setLed(shouldBeOn);
    }

    if (confirmNow) {
      pttX = currentX;
      pttY = currentY;
      Serial.printf("-> Posição do PTT SALVA! X=%d Y=%d\n\n", pttX, pttY);

      for (int flash = 0; flash < 3; flash++) {
        setLed(true);
        delay(80);
        setLed(false);
        delay(80);
      }

      stepConfirmed = true;
      while (digitalRead(PINO_PTT) == LOW) {
        delay(10);
      }
      delay(300);
    }

    delay(10);
  }

  saveCalibrationToNVS();
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

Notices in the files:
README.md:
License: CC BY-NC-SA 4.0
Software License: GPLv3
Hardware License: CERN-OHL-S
